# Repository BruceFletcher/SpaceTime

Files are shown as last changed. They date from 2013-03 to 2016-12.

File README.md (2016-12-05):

SpaceTime
=========

Clock design to help manage open hours at Vancouver Hack Space (VHS)

When this is done, it should be a design for a two line clock using 2.3" 7-segment LED
displays.  The two rows are:

* current time
* closing time (i.e. when the night's responsible keyholding member is planning to leave)

The clock is AVR-based and communicates over a serial link with a Raspberry Pi, which performs 
NTP time sync and updates variables on http://api.vanhack.com based on the clock's state.
http://isvhsopen.com references the VHS API to display the open state and the closing time. 

There is a separate readme for the [**Raspberry Pi setup instructions**](python/README.md) 
and [Python scripts](python).

Hardware design
---------------

The schematics and board layout are done in KiCAD.  The project has one main board with
the AVR MCU, power, LED drivers and various connectors on it, as well as a board designed
to hold four 7-segment LED characters for displaying a time value.  Two copies of this LED
board are required.

Enclosure design is TBD.  I'd like to do it with a Lamicoid faceplate, but it may end
up being easier to do it with laser-cut acrylic or plywood, since that seems to be what
is commonly available around VHS.

Software design
---------------

The firmware is currently a work in progress.  It is written in C for the avr-gcc
compiler.

Once complete it should support:

* Two rows of 7-segment output
* Keypad input
* Serial I/O, probably with an AT style interface
* Drift correction for the clock
* A reasonably intuitive interface for setting times and general use

The [Raspberry Pi's code](python) is written in Python and is described more [here](python/README.md).

See [bugs and to-do's](TODO.md) for remaining work.

Enclosure
---------

The enclosure is a laser cut box made from 5mm ply, primarily designed and built
by Luke Closs - thanks Luke!  The basic box design was created with
http://boxmaker.rahulbotics.com with the following parameters:

* Width: 350mm
* Height: 280mm
* Depth: 60mm
* Thickness: 5mm
* Notch length: 12.5mm (automatic)
* Cut width: 0.25mm

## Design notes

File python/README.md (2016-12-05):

## SpaceTime - Python Overview
The SpaceTime box contains a Raspberry Pi and a custom AVR-based PCB called [SpaceTime](../README.md). The Raspberry Pi runs a Python program that performs NTP time sync and facilitates network communication between SpaceTime and both the [isvhsopen.com Web API](http://isvhsopen.com/api/status/) ([GitHub](https://github.com/vhs/isvhsopen)) and the [Hackspace API](http://api.vanhack.ca) ([GitHub](https://github.com/vhs/api)). Communication with the Hackspace API is mostly deprecated in favour of the new isvhsopen Web API, but is still used to log the Raspberry Pi's local IP address. A local web server also provides a REST interface on port 80 to change the status from within the VHS local network.

The Raspberry Pi username/password and local IP address can be found on the physical SpaceTime box. The device is also configured with hostname ```isvhsopen-spacetime```. IP address is also on the Hackspace API as [spacetime_ip](http://api.vanhack.ca/s/vhs/data/spacetime_ip.txt). To connect to the Raspberry Pi from the local network, make sure you are on the same subnet by ensuring that `spacetime_ip` starts the same as your computer's IP. Then connect using any SSH client, such as `putty` or the Linux command line `ssh`.

## Configuring Raspberry Pi from scratch

#### Install Python packages from command line

```Shell
> sudo easy_install -U pyserial
> sudo easy_install -U requests
> sudo easy_install -U web.py
```

#### Enable UART serial on Raspberry Pi
To enable access of UART serial on GPIO pins through Python, edit system files:
http://www.irrational.net/2012/04/19/using-the-raspberry-pis-serial-port/

#### Set local timezone for Raspberry Pi
```Shell
> sudo ln -sf /usr/share/zoneinfo/America/Vancouver /etc/localtime
```
Check that NTP Daemon runs on startup. Ensure that `/etc/rc.conf` contains the line:
```Shell
DAEMONS=(!hwclock ntpd ntpdate)
```
Query system datetime:
```Shell
> date
```
If the date has drifted by more than 1000s, ntpd will not correct it by default. This will force time synchronization:
```Shell
> sudo ntpd -gq
```

#### Installing SpaceTime from GitHub
If Git is not installed:
```Shell
> sudo apt-get install git-core
```
Create directory for the Python code:
```Shell
> mkdir /usr/local/bin/SpaceTime
```
Navigate to the `/usr/local/bin` directory and perform Git Clone of this repo. The following will download only the latest version of the `/SpaceTime/tree/master/python` folder:
```Shell
> cd /usr/local/bin
> git clone --no-checkout --depth=1 https://github.com/<YOUR_ACCOUNT>/SpaceTime
> cd SpaceTime
> git config core.sparsecheckout true
> echo python > .git/info/sparse-checkout
> git checkout master
```
The code should now be at `/usr/local/bin/SpaceTime/python`
In the future, to download the latest code from GitHub:
```Shell
> cd /usr/local/bin/SpaceTime
> git pull
```
Note that you'll have to reapply the Web API Key after performing a ```git pull``` (see below).

#### Make program run on startup
Add to the end of `/etc/rc.local`
```Shell
> sudo nano /etc/rc.local

python /usr/local/bin/SpaceTime/python/main.py 80 &
```
The parameter after main.py is the port (80) for which to host the RESTful web server.

#### Get isvhsopen Web API Key
Refer to the [isvhsopen.com API on GitHub](https://github.com/vhs/isvhsopen) to obtain an API Key. Once obtained, run this command, replacing ```[Generated Key]``` with the actual API Key. HTTP POST commands to update the API will fail without a valid API Key.
```Shell
> cd /usr/local/bin/SpaceTime/python
> sudo sed -i 's/ISVHSOPEN_API_KEY/[Generated Key]/g' webapi.py
```
Please do not push changes to GitHub that include the API Key. This key should only be stored locally on the Raspberry Pi.

#### Configure VHS API variables
Find and edit the Hackspace API variable names used at the top of `main.py`. With the new isvhsopen.com API (independent of the Hackspace API), the only variable we still update directly on api.vanhack.ca is the one that stores the Raspberry Pi's local IP.

#### Set hostname for Raspberry Pi
To configure the Raspberry Pi with hostname ```isvhsopen-spacetime```:
Edit the 127.0.1.1 entry in `/etc/hosts`
```Shell
> sudo nano /etc/hosts

127.0.1.1       isvhsopen-spacetime
```
Replace the current hostname in `/etc/hostname` with ```isvhsopen-spacetime```
```Shell
> sudo nano /etc/hostname

isvhsopen-spacetime
```
Commit the changes and reboot
```Shell
> sudo /etc/init.d/hostname.sh
> sudo reboot
```
Now you should be able to ssh into the Raspberry Pi using either its [local IP address](http://api.vanhack.ca/s/vhs/data/spacetime_ip.txt) or hostname (```isvhsopen-spacetime```).

#### Testing
To run unit tests from command line:
```Shell
> python -m unittest test_timeutil
> python -m unittest test_vhsapi
> python -m unittest test_webapi
> python -m unittest test_spacetime
```

#### Debugging via serial
To speak directly to the SpaceTime board, connect via SSH to the Raspberry Pi, and then start a serial connection with `/dev/ttyAMA0` at `57600` baud. Ex:
```Shell
> screen /dev/ttyAMA0 57600
```

Type `AT?` and `<Enter>` to see help from the SpaceTime board.

Note that only one serial connection can be made at a time, so running screen will prevent the python script from communicating with the SpaceTime board. While using screen, the following commands are useful:
```
Exit:		Ctrl-a \
Detach:		Ctrl-a d
Reattach:	screen -x
List:		screen -ls
```

#### Using the REST API
The Python code hosts a web server on the local network. Anyone connected to the VHS network (anyone physically at the space) can connect to http://isvhsopen-spacetime/ to open the space, close the space, or change the closing time. Network admins, please do not expose this web service to the public internet. If you cannot access the URL, try [spacetime_ip](http://api.vanhack.ca/s/vhs/data/spacetime_ip.txt) on the Hackspace API and confirm that you're on the same network. Also try on port 8080, as this is the default if one is not specified on startup.

### TODO List

See [bugs and to-do's](../TODO.md).

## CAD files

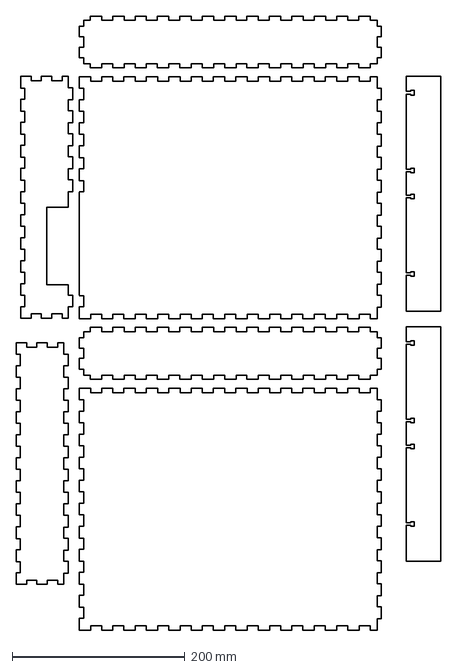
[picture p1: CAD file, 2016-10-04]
enclosure/vhs-clock-box-5mm.dxf
492.4 x 711.7 mm

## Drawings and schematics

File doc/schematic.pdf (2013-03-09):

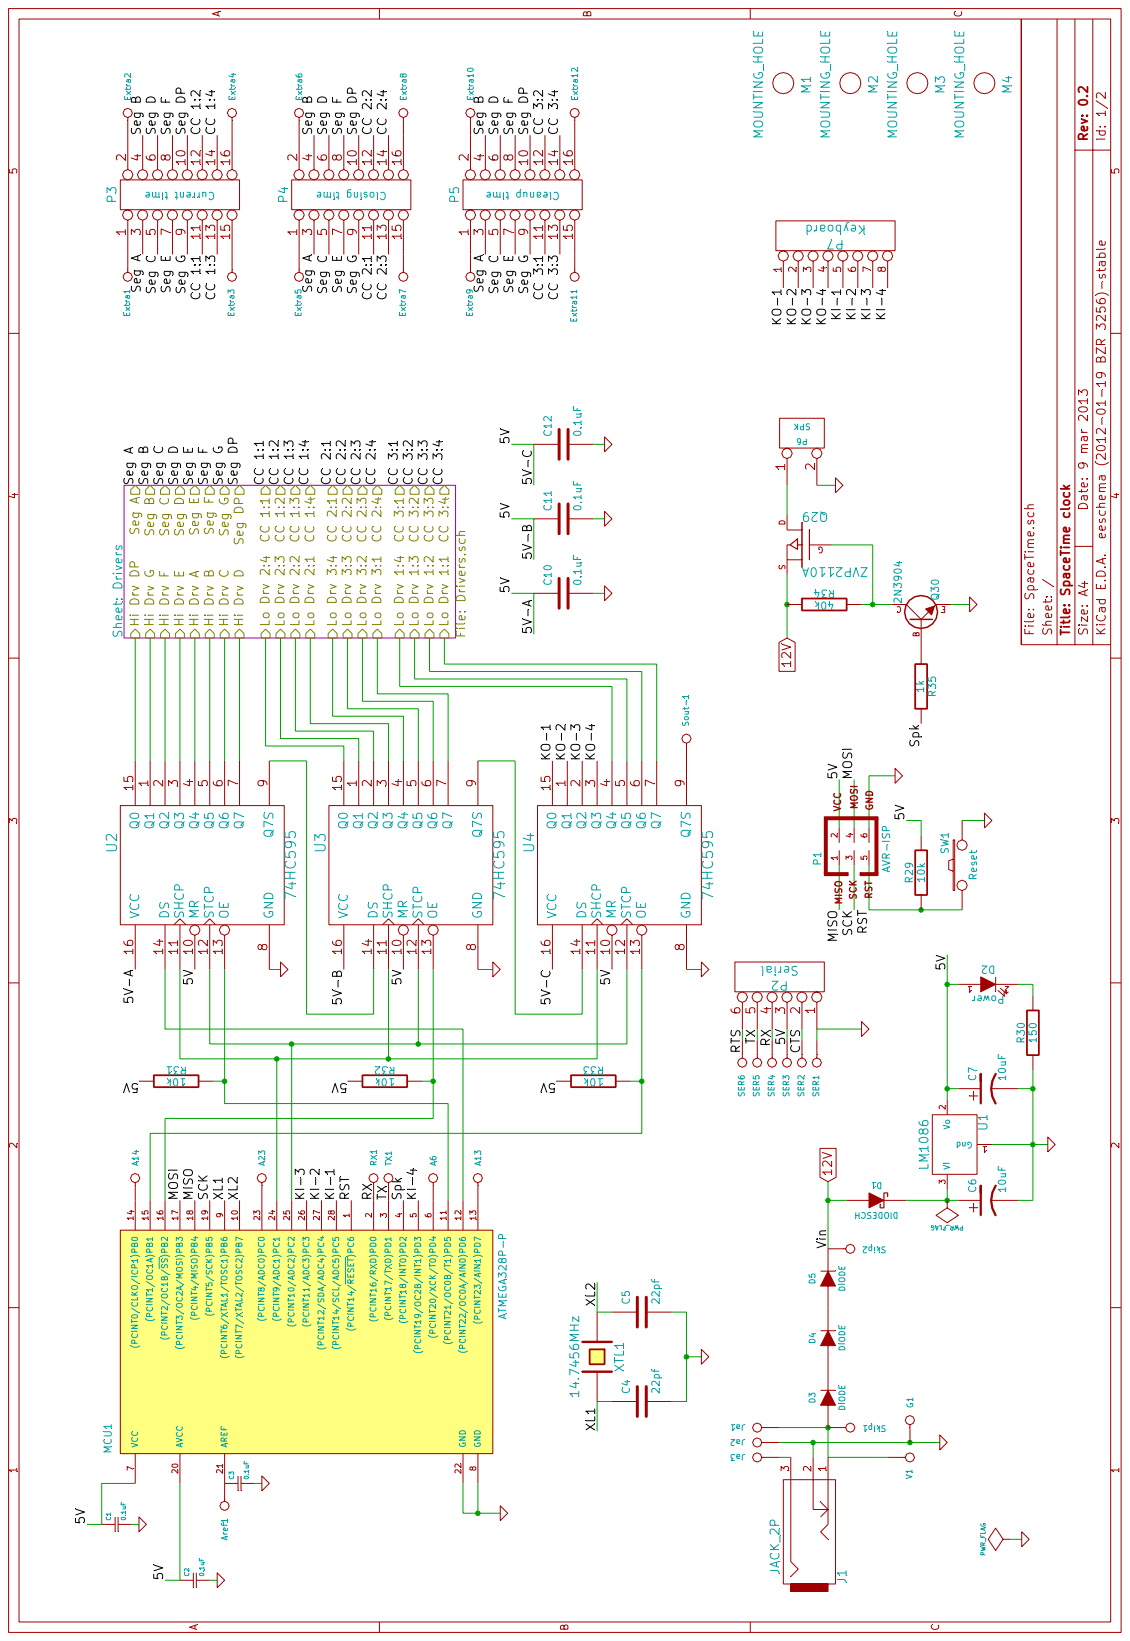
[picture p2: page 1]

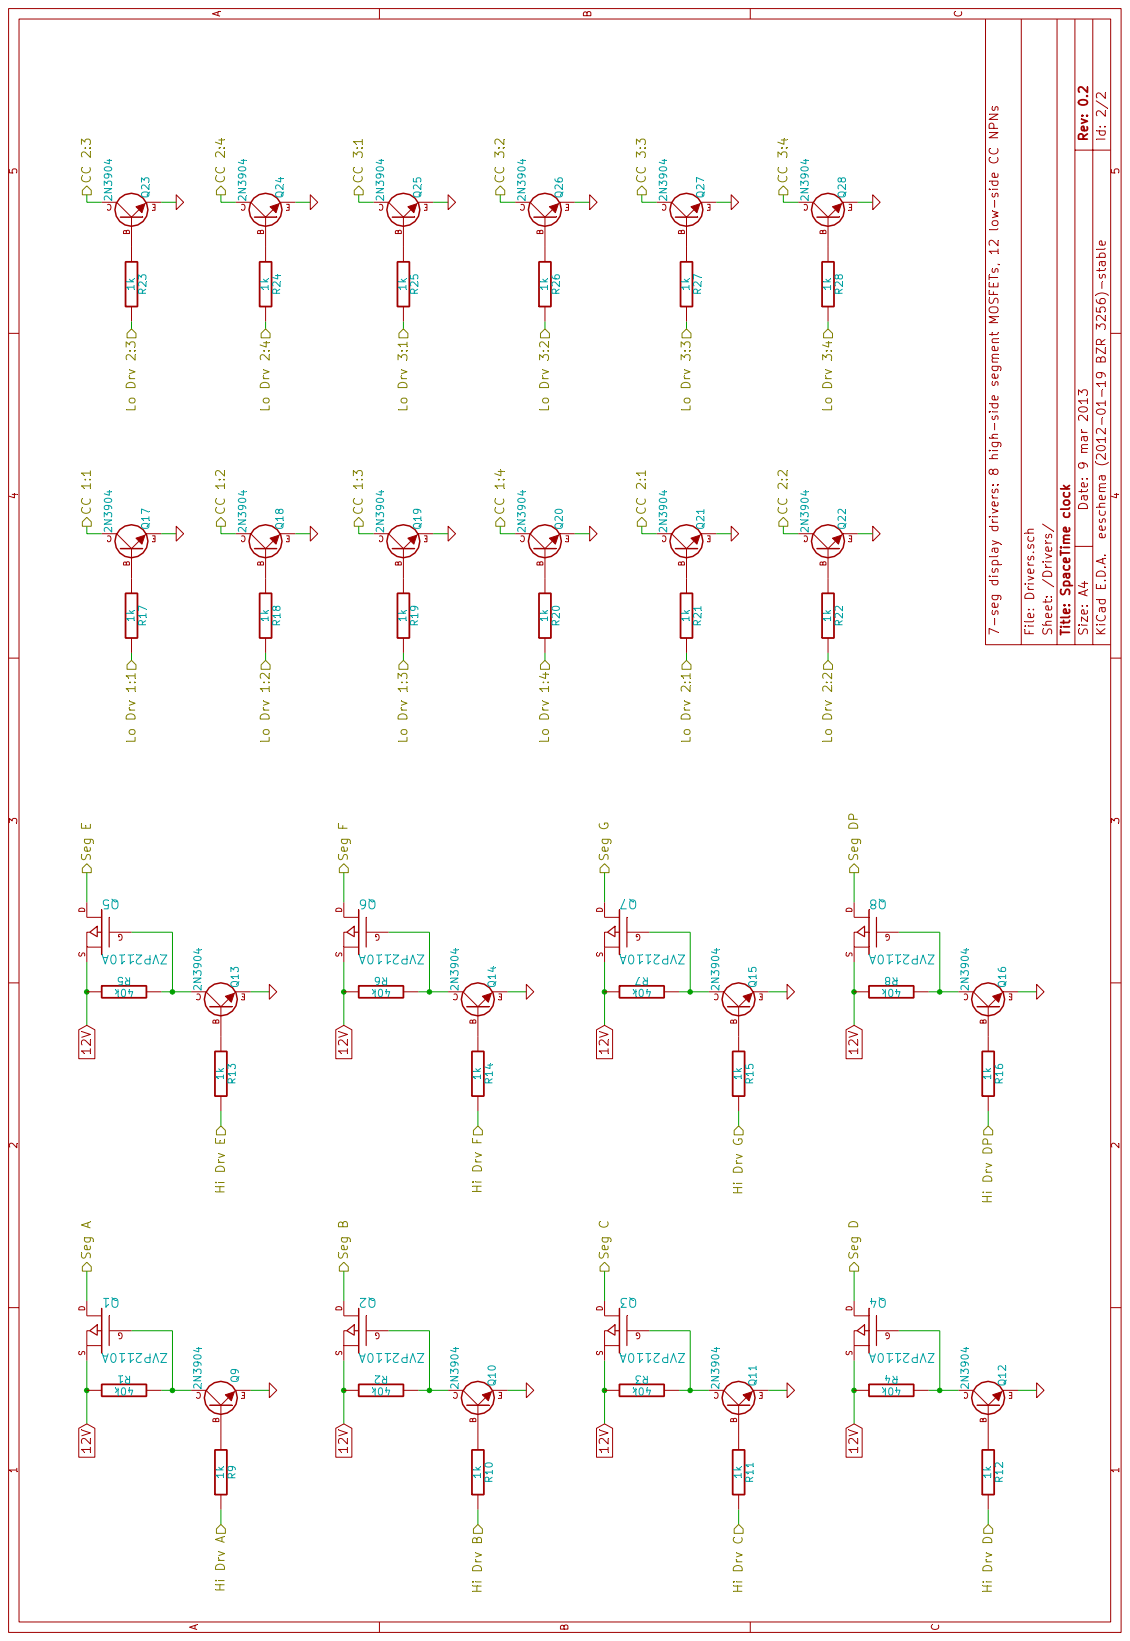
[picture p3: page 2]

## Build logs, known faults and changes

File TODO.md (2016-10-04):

### TODO List
In case someone wishes to configure the build environment for the SpaceTime AVR chip, the following is a list of minor bugs and UI improvements that would be nice to address in the AVR's C code:

- Make the whole active LED blink, not just the D segment (referred to as `underbar` in code), unless the active digit is blank.
- Make 6's have their A-segment turned on and 9's have their D-segment turned on.
- Consider 12hr time vs 24hr time (see what people think, after some use).
- Bug: When editing the time on a keypad, if you click Green or Red (to edit again), it resets the clock time in memory, but doesn't reset the clock display. So if you press Red, set the time, then press Red, then press Enter, it looks like you set it (except the colon is still off) but you didn't actually set it.
- Bug: When editing the time on a keypad, if you press the right arrow to set a one-digit hour, upon pressing Enter, it succeeds, but adds 10 hours to your time.
- Get rid of `cleanup_time` and `countdown_time` (they were planned features that never got implemented).
- When querying SpaceTime (`ATSTn?`) for a particular clock's time, it returns with either `'Not set'` or an `'HH:MM:SS'` time, but no label specifying which clock it refers to. It should respond with the clock name and time. (i.e. `'Closing time: 04:12:36'`)
 - Once Query response of `ATSTn?` is updated, the Python code can be updated to safely query Closing Time (`ATST1?`) on startup, and the `AmbiguousTime` type can be removed.
- Add warning beeps at 15/30min before time's up (currently only beeps when time's up).
- Make the `AT?` help better (see below).

Proposed new format for help command (when you type `AT?` in the serial console to SpaceTime):
```
SpaceTime commands:
  AT? - display this help
  AT  - display 'OK'
  ATST<n>?                  Query time
  ATST<n>=<hh:mm[:ss[.cc]]> Set time - .cc is 100ths of a second
  ATST<n>=x                 Clear time - intended for clearing closing time
  
  For all commands, valid values for n:
	0 - current, 1 - closing, 2 - cleanup, 3 - countdown
  
  Note: SpaceTime echoes all commands received. If you're using a serial 
        console, this is why you can see yourself typing).
```
**Note that if we remove `cleanup_time` and `countdown_time` from code, we should remove them from the help command as well.*

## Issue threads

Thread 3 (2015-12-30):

Bottom LED in third character does not turn on

JarrettR, 2015-12-30:
I hope it is a bad solder joint and not burnt out! That would be a mil nuisance!

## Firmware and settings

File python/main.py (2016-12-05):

import time
import socket
from spacetime import SpaceTime
from vhsapi import VHSApi #api.vanhack.ca
from webapi import WebApi #isvhsopen.com/api/status/
from restserv import RestServ #Webserver for REST API to allow updates from the VHS network 
from timeutil import *

dbg_showAllSerial = False #If true, prints out all received serial messages
lastClockSync   = 0       #Time of last clock sync with SpaceTime
lastHeartbeat   = 0       #Time of last update with isvhsopen.com WebApi
doorStatus_cache= ''      #The last known door status, to send periodic heartbeat to WebApi
api_var_ip      = 'spacetime_ip'
max_clock_drift = 10 #Allowable error (in seconds) between SpaceTime clock and system clock

def UpdateDoorStatus(webApi, closing_time):
  #Save current time and door status to send periodic heartbeats to WebAPI
  global lastHeartbeat, doorStatus_cache
  lastHeartbeat = time.time()
  doorStatus_cache = closing_time
  #Update WebAPI with door status. WebAPI is smart enough
  #to ignore duplicate submissions, so unnecessary updates
  #aren't harmful and do not affect the timestamp.
  if closing_time == None:
    webApi.Update('closed')
  else:
    #Removing seconds part
    closing_time = closing_time[:5]
    webApi.Update('open', closing_time)
    
def ProcessSerialMsg(msg, webApi, st):
  
  if msg.type == 'Current' or msg.type == 'AmbiguousTime':
    #SpaceTime is telling us what it thinks is the current time
    #It's telling us either because the user just set it, or
    #because we asked it.
    #Currently, we never ask for the Closing time, so if we receive
    #an AmbiguousTime, we can safely assume it is the Current time.

    global lastClockSync
    lastClockSync = time.time()
    curTime = time.localtime(lastClockSync)
    
    shouldUpdate = True
    if msg.val != None:
      #Check if SpaceTime time is close to current system time
      SpaceTimeDrift = TimeOffsetSeconds(curTime, StrToTime(msg.val))
      #Don't bother updating SpaceTime if time is within 10s of system time
      shouldUpdate = abs(SpaceTimeDrift) > max_clock_drift
    if shouldUpdate:
      print('Synchronizing SpaceTime\'s clock to ' + TimeToStr(curTime))
      #SpaceTime Current clockID = 0
      st.SetTime(0, curTime)
    
  elif msg.type == 'Closing':
    #SpaceTime is telling us the status of closing time.
    #It's telling us because the user just set it, because
    #we asked for it, or because it just expired.
    
    print('SpaceTime reports that Closing time is ' + ('not set' if msg.val == None else msg.val))
    #Update WebAPI
    UpdateDoorStatus(webApi, msg.val)
  elif msg.type == 'OK':
    return #Can ignore 'OK' responses
  elif msg.type == 'Echo':
    return #SpaceTime echoes all commands sent to it, so we can ignore these
  elif msg.type == 'Boot':
    print('SpaceTime has just been reset!')
    print('Resetting Web API variables and setting SpaceTime\'s clock')
    UpdateDoorStatus(webApi, None)
    #Query SpaceTime's clock. Its response will trigger us to update it if necessary.
    st.GetTime(0)
    return
  else:
    print('Serial message ignored: "' + msg.val + '"')

def GetLocalIP():
  #Returns the machine's local IP address as a string, or 'unknown' if error.
  ip = 'unknown'
  try:
    s = socket.socket(socket.AF_INET, socket.SOCK_DGRAM)
    s.connect(('8.8.8.8', 80))
    ip = s.getsockname()[0]
    s.close()
  except Exception as e:
    print('IP lookup failed: ', e)
  return ip

def ShouldSyncClock():
  #Sync the clock every 24h, and do it when we're around 
  #40-50s in the current minute (to minimize the chance of the clock
  #jumping back 1min or forward 2min).
  _24h = 86400 #seconds in 24h
  curTime = time.time()
  if curTime - lastClockSync > _24h:
    curTime = time.localtime(curTime)
    if 40 < curTime.tm_sec < 50:
      return True
  return False
  
def ShouldSendHeartbeat():
  #Send a heartbeat to isvhsopen.com every 15min
  _15min = 900 #seconds in 15min
  curTime = time.time()
  return (curTime - lastHeartbeat > _15min)

def setup():
  #Connects to the internet, updates local IP address 
  #on VHS Api, connects to SpaceTime Serial, updates
  #Web Api variables, and queries SpaceTime's clock
  #(to trigger an update upon its response).
  #returns initialized (WebAPI, SpaceTime)
  
  print('Initializing SpaceTime...')
  vhs = VHSApi()
  web = WebApi()
  st = SpaceTime()

  print('Connecting to the internet...')
  web.WaitForConnect()
  print('Connected!')
  #Update the machine's local IP on the VHS Api. The timestamp can serve as a boot history.
  vhs.Update(api_var_ip, GetLocalIP())
  
  print('Initializing Serial connection with SpaceTime (' + st.serial.name + ')...')
  while not st.IsConnected():
    print('Failed to init Serial connection with SpaceTime. Trying again...')
  print('Initialized!')
  
  print('Initializing webserver for REST API (only available to LAN)')
  RestServ(st)
  
  #Query Closing time (this is the only time we do this)
  #in case RPi was rebooted but SpaceTime wasn't.
  st.GetTime(1)    #Closing time is ID 1
  st.Read()        #Ignore the echo of the GetTime command
  ct = st.Read()   #Read the response
  #It is an unlabeled time, but we know it should be Closing time
  if ct.type == 'AmbiguousTime':
    ct.type = 'Closing'
    #Update Web Api if necessary
    ProcessSerialMsg(ct, web, st)
  
  #Query SpaceTime's clock. Its response will trigger us to update it if necessary.
  st.GetTime(0)  #Current time is ID 0
  return web, st

def loop(web, st):
  #Check for new Serial messages every second.
  #If there is a Serial message to read, read and process it.
  if st.CanRead():
    msg = st.Read()
    if dbg_showAllSerial:
      dbgmsg = 'SerialDbg ' + msg.type + ': ' + str(msg.val)
      print(dbgmsg if not dbgmsg.endswith('\r\n') else dbgmsg[:-2])
    ProcessSerialMsg(msg, web, st)
  elif ShouldSyncClock():
    #Query SpaceTime's clock. Its response will trigger us to update it if necessary.
    st.GetTime(0)
    #Give SpaceTime enough time to respond so that we only send one st.GetTime(0) per sync period.
    time.sleep(0.5)
  elif ShouldSendHeartbeat():
    print('Sending Heartbeat to Web API...')
    UpdateDoorStatus(web, doorStatus_cache);
  else:
    time.sleep(1)

def main():
  #Run setup and then loop indefinitely
  web, st = setup()
  
  #Loop indefinitely - Catch and report any unhandled exceptions,
  #but try to keep going anyway.
  while 1:
    try:
      loop(web, st)
    except Exception as e:
      print('Exception in main loop! ', e)
      #Give some time for whatever caused the error to go away.
      #Also don't want to flood a log file with identical exceptions.
      time.sleep(5)

if __name__ == '__main__': 
  main()

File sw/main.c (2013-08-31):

/**
 * SpaceTime - A two-row 7-segment LED clock for tracking open hours at VHS.
 *
 * By Bruce Fletcher
 */

#include <stdio.h>
//#include <string.h>
#include <avr/interrupt.h>
#include "uart.h"
#include "shift.h"
#include "timer.h"
#include "display.h"
#include "keypad.h"
#include "serial.h"
#include "edit.h"
#include "clock.h"
#include "watchdog.h"


/**
 * Watchdog timeout function; disable the display and chirp a bit
 * as a diagnostic.
 */
void oops(void)
{
  shift_disable();
  timer_beep(5);
}

int main(void)
{
  uart_init();
  shift_init();
  timer_init();
  display_init();
  keypad_init();
  serial_init();
  edit_init();
  clock_init();
  watchdog_init(WDTO_15MS, &oops);

  sei();  // enable interrupts

  printf("\r\n*** BOOTED ***\r\nSpaceTime, yay!\r\n");

  timer_beep(10);

  while(1)
  {
    display_update();

    serial_update();

    edit_update();

    clock_update();
  }
}

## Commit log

2013-02-09 Initial checkin of hardware design - missing inputs and 7 segment display boards
    [Drivers.sch, SpaceTime.sch]
2013-02-11 Copied the project over to my Mac's KiCAD install, added a couple junctions to get a clean compile
    [Drivers.sch, SpaceTime.sch]
2013-02-11 Added bypass caps on shift registers (optional, but easier to add now) Messed with junctions that were needed for ERC to pass (on recent Mac build, but not on older Windows build)
    [Drivers.sch, SpaceTime.sch]
2013-02-11 Added schematic for 7-segment display holder boards
    [Display.sch]
2013-02-14 Changed connectors to style I could get locally Swapped on-board 12v regulation for external 12v regulated supply
    [Display.sch, Drivers.sch, SpaceTime.sch]
2013-02-14 Updated Readme with more detail of what I'm up to Renamed one connector on the main board
    [Drivers.sch, SpaceTime.sch]
2013-02-16 Added footprints to components
    Some caps probably need to be converted to electolytic, maybe some other
    issues. It's a bit of a rough footprint assignment at the moment.
2013-02-24 Initial PCB part layout
    Still no keyboard or audio out, but I have ideas for those that
    shouldn't cause too much havoc with my schematic. I hope.
    [Drivers.sch, SpaceTime.brd, SpaceTime.sch]
2013-03-04 Partially routed PCB
    Should be able to tighten up the board outline a bit from here, we'll
    see.
    [Drivers.sch, SpaceTime.brd, SpaceTime.sch]
2013-03-08 PCB is starting to shape up
    Need to sort out PWM for shift registers, then some power and ground.
    [Drivers.sch, SpaceTime.brd, SpaceTime.sch]
2013-03-09 PCB passes DRC!
    Need to nail down pad on 5V regulator, if nothing else.
    [Drivers.sch, SpaceTime.brd, SpaceTime.sch]
2013-03-09 Added/updated revision field to 0.2. Progress!
    [Drivers.sch, SpaceTime.brd, SpaceTime.sch]
2013-03-09 Updated schematic PDF
2013-03-12 Tweaked ground plane around timing crystal.
    There seems to be some problem synching this to github. Maybe try
    later?
    [SpaceTime.brd]
2013-04-21 Shrunk board, went with SMT driver section
    Lots of changes...
    Shrank board to fit ITEAD Studio 10x10cm board size
    Dropped 3rd shirt register, use segment scan for keyboard
    Switched repetitive driver sections to SMT parts
    [Drivers.sch, SpaceTime.brd, SpaceTime.sch]
2013-05-21 Board design completed (I hope)
    This is the 1.0 version of the board, as mailed off for PCB
    manufacturing.
    [Drivers.sch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]
2013-07-16 UART support includes interrupt-driven TX Basic keypad scanning works Some amount of documentation and renaming for clarity
2013-07-20 So that *was* my bug, what with the delayed character output and all!
    [uart.c]
2013-07-21 Didn't catch serial.[ch] in last commit
    [serial.c]
2013-08-11 Added the ability to beep for N hundredths of a second, beep on start and keypresses Implemented brightness, blinking and underscores for the display Added keypad time editing behaviours for current 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
2013-08-17 Refactored a bunch of code that didn't belong in main.c Made keypad and serial time updates mutually consistent Cleaned up a bunch of time editing behaviours
    [main.c]
2013-08-18 Added the enclosure design Luke helped pull together tonight
    [vhs-clock-box-5mm.dxf]
2013-08-31 Added watchdog interrupt support to protect display segments from being stuck on.
    [main.c, shift.c]
2014-01-25 Added rails for enclosure to hold the LCD screen
    [vhs-clock-box-5mm.dxf]
2015-12-01 Fixed typos in comments
    [spacetime.py]
2015-12-17 Make web service a background task
    I didn't realize that starting the web application blocked execution for
    everything else. It's now running in its own thread.
    [restserv.py, test_webapi.py]
2016-12-05 Updated with hackspace.ca domain change
    [SpaceTime.brd]
